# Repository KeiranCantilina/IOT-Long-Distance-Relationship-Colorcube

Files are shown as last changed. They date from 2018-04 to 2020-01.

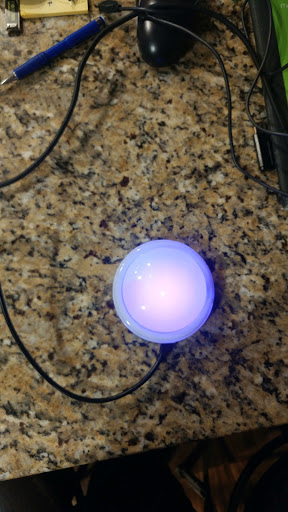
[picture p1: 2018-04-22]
prototype colorcube.jpg

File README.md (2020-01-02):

# IOT Long Distance Relationship Colorcube
Design for a pair of networked RGB LED widgets that synchronously change color when one of them is squeezed.

I know there are similar things out there, but I'm intentionally forging forward without looking at other implementations in order to force myself to properly learn this stuff.

~~The current design uses a Wildfire v4 (an Arduino-flavor board made by WickedDevice). This device is not super well-suited to this project,
but it has an integrated ESP8266 wifi chip and a microSD thingy and also I have like 5 of them somehow, so that's what I'm using.~~

The newest version of the design uses an Adafruit Feather HUZZAH ESP8266 board. In contrast to the Wildfire, this board is very well suited to this project and costs less than $20. Instead of a generic RGB LED driven using PWM, the newest hardware revision now uses a "NeoPixel" WS2812 RGB LED breakout board. 

HARDWARE DESIGN (Prototype completed!)
---------------------
The devices each consist of a plastic 3D printed base (containing the microcontroller board) with an RGB led protruding from the base. The LED is covered by a silicon cube-shaped diffuser, which also contains a motion sensor to detect squeezing. Power is provided by 5V USB. A small Li-ion battery might be included.

SOFTWARE DESIGN (Done! See Prototype_ESP8266_V2.ino)
---------------------
The software side of things should be pretty simple. The Wildfire collects sensor data and randomly generates 3 values (for RGB) when a squeeze is detected. These values are published via MQTT to a feed on io.adafruit.com. The device is also subscribed to the same feed, and will collect both values it publishes and values from other cubes. When data is recieved through the subscription, the device parses the data and uses the RGB values to change its own color.

ENCLOSURE DESIGN (Prototype completed! See 3mf files)
---------------------
The enclosure consists of a two-part 3D printed shell with holes for wires (and to provide access to the USB port) and standoffs for boards. There is a sort of brim thingy to hold the silicone cube using a friction fit. This design will probably go through several refinement stages. Holes in the standoffs (for screws) will be drilled by hand because the 3D printer is bad at holes.

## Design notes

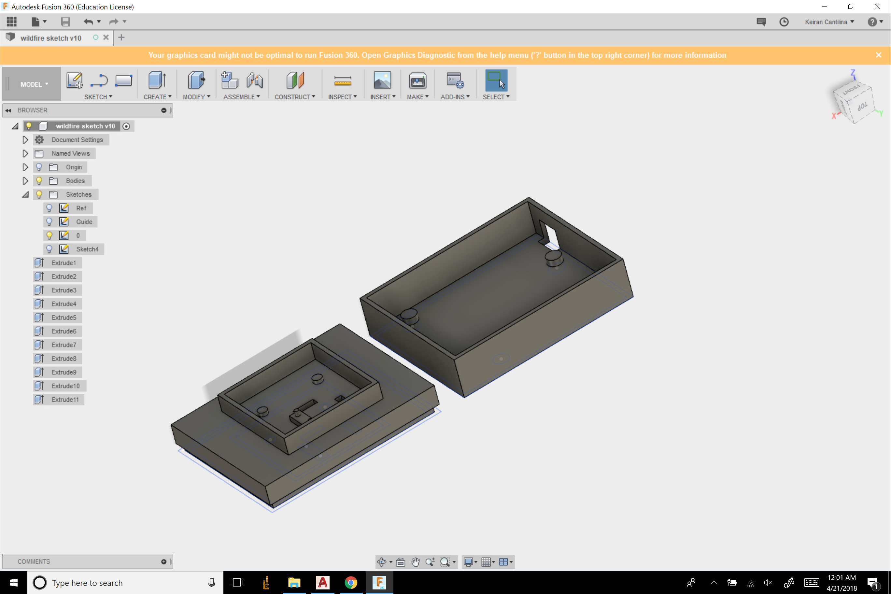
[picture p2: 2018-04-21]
enclosure design in progress.png

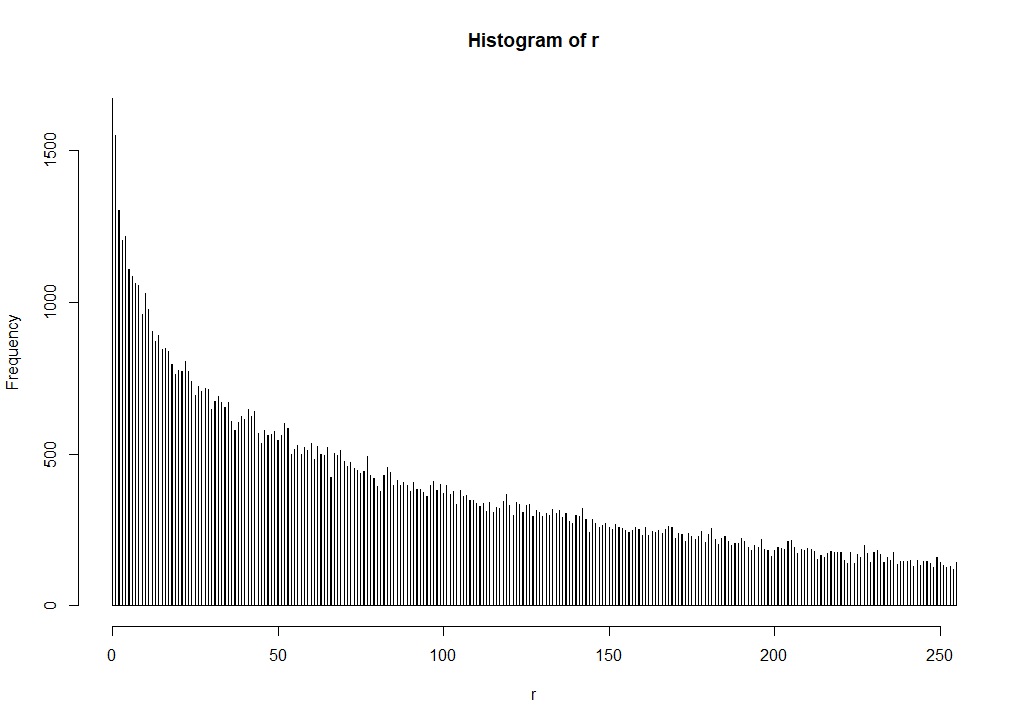
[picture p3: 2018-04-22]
Histogram of red.png

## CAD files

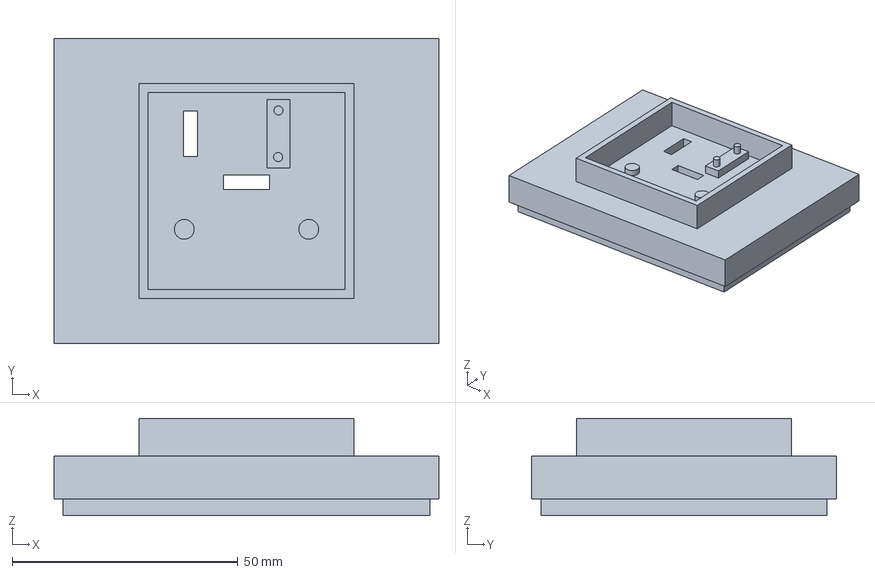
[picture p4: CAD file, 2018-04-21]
UM2E_colorcube_top_V1.3mf
85.3 x 67.6 x 21.6 mm

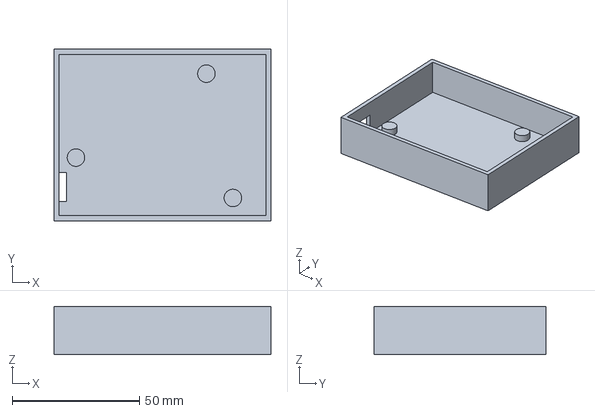
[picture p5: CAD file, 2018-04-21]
UM2E_colorcube_bottom_V1.3mf
85.3 x 67.6 x 19.0 mm

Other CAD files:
wildfire sketch.dwg

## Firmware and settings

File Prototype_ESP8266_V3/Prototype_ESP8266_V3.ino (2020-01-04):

/*This is the third generation codebase for the LED Relationship Light Project.
  This codebase is compatible with the Adafruit Feather HUZZAH (and theoretically with other ESP8266-based boards) and NeoPixel RGB-LEDs.
  Adafruit.io is used as the MQTT server, and the WifiManager library is used to handle user-side Wifi config via a captive portal that pops up
  if connection fails.

  This third generation code differs from the second generation in that it includes some fun extras, like crossfading transitions.
    
  The most recent hardware uses these WS2812 Neopixels: https://www.adafruit.com/product/1612

  Pins used:
  IDE pin 14 (marked on board as 14)(Physical Pin 5): WS2812 DataIn
  VBUS (marked on board as USB)OR 3V3(if 5V fails)  : WS2812 Power In
  GND                                               : WS2812 GND
  IDE pin 4 (marked on board as 4)(Physical pin D13): Button GND
  IDE pin 5 (marked on board as 5)(Physical pin D14): Button Detect (Interrupt attached and using internal pullup)
  IDE pin 0 (marked on board as 0)(Physical pin D3) : Status LED (built-in power LED, write HIGH to turn off ONLY AFTER BOOT)
  
*/


/********************* Libraries ****************************/
#include <ESP8266WiFi.h>          //ESP8266 Core WiFi Library (you most likely already have this in your sketch)

#include <DNSServer.h>            //Local DNS Server used for redirecting all requests to the configuration portal
#include <ESP8266WebServer.h>     //Local WebServer used to serve the configuration portal
#include <WiFiManager.h>          //https://github.com/tzapu/WiFiManager WiFi Configuration Magic

#include <Adafruit_MQTT.h>
#include <Adafruit_MQTT_Client.h> // Found at https://github.com/adafruit/Adafruit_MQTT_Library

#include <Adafruit_NeoPixel.h>

/********************* LED Setup ****************************/
#define NEOPIXEL_PIN 14 // NeoPixels are connected to this pin
#define LED_COUNT 1
#define BUTTON_PIN 5
#define BUTTON_GND 4
#define DEBOUNCE_DELAY 100 // in ms
#define STATUS_LED 0

Adafruit_NeoPixel RGBlight(LED_COUNT, NEOPIXEL_PIN, NEO_GRB + NEO_KHZ800); // Declare Neopixel object

uint32_t last_interrupt_time = 0;
uint8_t led_status = 0; //  Debugging LED flag
volatile int flag = 0;
volatile long times_run = 0;

int current_color[3] = {0,0,0};
int blue_array[3] = {0,0,255};
int red_array[3] = {255,0,0};

/************************* Adafruit.io Setup *********************************/
#define AIO_SERVER      "io.adafruit.com"
#define AIO_SERVERPORT  1883                   // use 8883 for SSL
#define AIO_USERNAME    "Keirancantilina"
#define AIO_KEY         "5526f708aeb648ea907a38d95af2b5a2"

/************ Global State (you don't need to change this!) ******************/
// Create an ESP8266 WiFiClient class to connect to the MQTT server.
WiFiClient client;
// or... use WiFiFlientSecure for SSL
//WiFiClientSecure client;

// Setup the MQTT client class by passing in the WiFi client and MQTT server and login details.
Adafruit_MQTT_Client mqtt(&client, AIO_SERVER, AIO_SERVERPORT, AIO_USERNAME, AIO_KEY);

/****************************** Feeds ***************************************/

// Setup a feed called 'publish_feed' for publishing.
// Notice MQTT paths for AIO follow the form: <username>/feeds/<feedname>
Adafruit_MQTT_Publish publish_feed = Adafruit_MQTT_Publish(&mqtt, AIO_USERNAME "/feeds/keiran-block");

// Setup a feed called 'subscribe_feed' for subscribing to changes.
Adafruit_MQTT_Subscribe subscribe_feed = Adafruit_MQTT_Subscribe(&mqtt, AIO_USERNAME "/feeds/keiran-block");


// Bug workaround for Arduino 1.6.6, it seems to need a function declaration
// for some reason (only affects ESP8266, likely an arduino-builder bug).
void MQTT_connect();


void setup() {

/********************* RGB and Button Init ****************************/
  // Initialize Neopixel
  RGBlight.begin();
  RGBlight.clear();
  RGBlight.show();
  
  // Setup the button with an internal pull-up :
  pinMode(BUTTON_PIN,INPUT_PULLUP);

  // Setup interrupt handling and LED for debug purposes
  //pinMode(LED_BUILTIN, OUTPUT);
  attachInterrupt(digitalPinToInterrupt(BUTTON_PIN), isr_handler, CHANGE); // CHANGE for dome lights, RISING for little button switches
  pinMode(STATUS_LED, OUTPUT);

  // This is our fake ground connection for the switch
  pinMode(BUTTON_GND, OUTPUT);
  digitalWrite(BUTTON_GND, LOW);

  // Start with LED red to show setup
  RGBlight.setPixelColor(0,RGBlight.gamma32(RGBlight.Color(red_array[0],red_array[1],red_array[2])));
  RGBlight.show();
  memcpy(current_color,red_array,sizeof(current_color));

/********************* Serial Setup ****************************/  
  //Initialize Serial comms
  Serial.begin(115200);

  //Give things time to warm up (this is purely magical thinking, I know)
  delay(10);
  Serial.println(F("Keiran's Long-Distance Friendship Cube"));
  
/********************* Wifi Setup ****************************/
  //Initialize WifiManager captive portal
  WiFiManager wifiManager;

  //Callback to function that executes right before config mode
  wifiManager.setAPCallback(configModeCallback);

  //first parameter is name of access point, second is the password
  wifiManager.autoConnect("ESP8266_KKC", "password");

  Serial.println("WiFi connected! Yay");
/********************* END Wifi Setup ****************************/

  // Setup MQTT subscription for subscribe_feed.
  mqtt.subscribe(&subscribe_feed);
}



//Initialize variable used for payload value (RGB color)
volatile long x=0;


// Main program loop
void loop() {
  
  //THis used to be a function but for whatever reason it broke mqtt connection even before it was ever called...somehow it works just pasted in...
  // x = rand_color();

  //Randomly generate RGB values for output as the payload. Values are 0-255 with 111 added to eliminate problems with 0 padding.
  long red_int = random(111,366);
  long green_int = random(111,366);
  long blue_int = random(111,366);

  long million = 1000000;
  long thousand = 1000;
  
  // Ints get concatenated together into the payload "string". For whatever reason strings and chars are no good so this whole thing is a giant long. WHYYYY
  x = (red_int*million)+(green_int*thousand)+(blue_int);
  
  mqtt.subscribe(&subscribe_feed);
  // this is our 'wait for incoming subscription packets' busy subloop
  // try to spend your time here
  
  // Ensure the connection to the MQTT server is alive (this will make the first
  // connection and automatically reconnect when disconnected).  See the MQTT_connect
  // function definition further below.
  MQTT_connect();
  

  Adafruit_MQTT_Subscribe *subscription;

  
  
  while (flag == 0 && (subscription = mqtt.readSubscription(1000))) {
    if (subscription == &subscribe_feed) {
      Serial.println();
      Serial.print(F("Message recieved: "));
      Serial.println((char *)subscribe_feed.lastread);
      Serial.println();

      // Write received color to LED
      int new_color[3];
      new_color[0] = string_to_red((char *)subscribe_feed.lastread)-111;
      new_color[1] = string_to_green((char *)subscribe_feed.lastread)-111;
      new_color[2] = string_to_blue((char *)subscribe_feed.lastread)-111;


      // LED crossfade (is inline because it was too slow as a function, for some reason)
      int greatest;
      int color_difference[3] = {new_color[0]-current_color[0],new_color[1]-current_color[1],new_color[2]-current_color[2]};
  
      if(abs(color_difference[0])>= abs(color_difference[1])){
        if(abs(color_difference[0])>= abs(color_difference[2])){
          greatest = color_difference[0];
        }
        else{
          greatest = color_difference[2];
         }
      }
      else{
        if(abs(color_difference[1])>= abs(color_difference[2])){
          greatest = color_difference[1];
        }
        else{
          greatest = color_difference[2];
        }
      }
  
      for (int i=0; i< abs(greatest); i++){
        for (int j=0; j<3;j++){
          if (current_color[j] != new_color[j]){
            current_color[j] = current_color[j] + sgn(color_difference[j]);
          }
        }

        RGBlight.setPixelColor(0,RGBlight.gamma32(RGBlight.Color(current_color[0],current_color[1],current_color[2])));
        RGBlight.show();
        delay(10);
      }
      // ---------------------------------------------------------------------------------------
    }  
  }

  //If first time running, turn LED blue to indicate ready status and turn off status red LED
  if (times_run == 0){
    RGBlight.setPixelColor(0,RGBlight.gamma32(RGBlight.Color(blue_array[0],blue_array[1],blue_array[2])));
    RGBlight.show();
    memcpy(current_color, blue_array, sizeof(current_color));
    
    digitalWrite(STATUS_LED, HIGH);
  }
  
  if (flag == 1){
    //x = rand_color();
    Serial.print(F("\nSending color value: "));
    Serial.print(x);
    Serial.print("...");
    //if (! publish_feed.publish((char *)x)) {
    char buffer [10];
    int ret = snprintf(buffer, sizeof(buffer), "%ld", x);
    char * const p = buffer;
    if (! publish_feed.publish(p)) {
      Serial.println(F("Failed"));
      Serial.println();
    } else {
      Serial.println(F("OK!"));
      Serial.println();
    }
    flag = 0;
  }
    

  Serial.println("No message so far! Will look again...");

  // Increment times run counter
  if(times_run == 0){
    times_run++;
  }
  
  
  // ping the server to keep the mqtt connection alive
  // NOT required if you are publishing once every KEEPALIVE seconds
  
//  if(! mqtt.ping()) {
//    mqtt.disconnect();
//  }
  
}




// Function to connect and reconnect as necessary to the MQTT server.
// Should be called in the loop function and it will take care if connecting.
void MQTT_connect() {
  int8_t ret;

  // Stop if already connected.
  if (mqtt.connected()) {
    return;
  }

  Serial.print("Connecting to MQTT...");

  uint8_t retries = 3;
  
  while ((ret = mqtt.connect()) != 0) { // connect will return 0 for connected
       Serial.println(mqtt.connectErrorString(ret));
       Serial.println("Retrying MQTT connection in 5 seconds...");
       mqtt.disconnect();
       delay(5000);  // wait 5 seconds
       retries--;
       if (retries == 0) {
         RGBlight.setPixelColor(0,RGBlight.gamma32(RGBlight.Color(red_array[0],red_array[1],red_array[2]))); // Red light for error
         RGBlight.show();
         memcpy(current_color,red_array,sizeof(current_color));
         while (1);
       }
  }
  Serial.println("MQTT Connected!");
  Serial.println();
}



// Functions to take string with color data and turn it into rgb values
int string_to_red(char color_string[]){
  char r[]={0,0,0};
  for (byte q = 0; q < 3; q = q + 1) {
    r[q] = color_string[q];
  }
  return atol(r);
}
int string_to_green(char color_string[]){
  char g[]={0,0,0};
  for (byte q = 0; q < 3; q = q + 1) {
    g[q] = color_string[q+3];
  }
  return atol(g);
}
int string_to_blue(char color_string[]){
  char b[]={0,0,0};
  for (byte q = 0; q < 3; q = q + 1) {
    b[q] = color_string[q+6];
  }
  return atol(b);
}



// Interrupt handling
ICACHE_RAM_ATTR void isr_handler() {
  uint32_t interrupt_time = millis();
  // Debounce
  if (interrupt_time - last_interrupt_time > DEBOUNCE_DELAY) {
    led_status = !led_status;
    //digitalWrite(LED_BUILTIN, led_status);  // Enable this for visual debugging switch/interrupt stuff
    flag = 1;
  }
  last_interrupt_time = interrupt_time;
}



// Function for handling failed wifi connections
void configModeCallback (WiFiManager *myWiFiManager) {
  Serial.println("Entered config mode");
  Serial.println(WiFi.softAPIP());
  // Placeholder for future callback code here (debug, maybe)
  Serial.println(myWiFiManager->getConfigPortalSSID());
}



// Sign finding function
inline int sgn(int val) {
  if (val < 0) return -1;
  if (val==0) return 0;
  return 1;
}

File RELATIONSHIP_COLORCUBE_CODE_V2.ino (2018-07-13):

/***************************************************
 * Wicked Device Wildfire v4 MQTT-Adafruit.io Example
 * 
 * 
 * This is the Adafruit MQTT Library ESP8266 Example, 
 * modified to work on the Wildfire v4 boards made by WickedDevice
 * (http://shop.wickeddevice.com/) using the WickedDevice ESP8266 AT Client
 * library (found at https://github.com/WickedDevice/ESP8266_AT_Client).
 * 
 * This bit of code serves as an example of how to get the Wildfire v4 to 
 * work with io.adafruit.com using MQTT, since the code shipped with the 
 * boards (supporting the sparkfun.io Phant servers) is now obsolete.
 * 
 * Written/rehashed/butchered by Keiran Cantilina
 * Attribution-NonCommercial licesnse 3.0 United States (CC BY-NC 3.0 US)
 * 
 * Boilerplate from original Adafruit MQTT Library ESP8266 Example code
 * is included below. Please include both the above and below text in any
 * redistribution. 
 * 
 */


/***************************************************
  Adafruit MQTT Library ESP8266 Example

  Must use ESP8266 Arduino from:
    https://github.com/esp8266/Arduino

  Works great with Adafruit's Huzzah ESP board & Feather
  ----> https://www.adafruit.com/product/2471
  ----> https://www.adafruit.com/products/2821

  Adafruit invests time and resources providing this open source code,
  please support Adafruit and open-source hardware by purchasing
  products from Adafruit!

  Written by Tony DiCola for Adafruit Industries.
  MIT license, all text above must be included in any redistribution

 ****************************************************/
 
 
#include "Adafruit_MQTT.h"
#include "Adafruit_MQTT_Client.h" // Found at https://github.com/adafruit/Adafruit_MQTT_Library
#include <ESP8266_AT_Client.h> // Found at https://github.com/WickedDevice/ESP8266_AT_Client
#include <RGBLED.h> // Found at https://github.com/BretStateham/RGBLED
#include <EnableInterrupt.h>


// sketch must instantiate a buffer to hold incoming data
// 1500 bytes is way overkill for MQTT, but if you have it, may as well
// make space for a whole TCP packet
#define ESP8266_INPUT_BUFFER_SIZE (1500)
uint8_t input_buffer[ESP8266_INPUT_BUFFER_SIZE] = {0};     


/************************* Init LED & switch stuff****************************/

RGBLED rgbLed(9,10,8,COMMON_CATHODE); // 9,10,8 for smd led chip, 8,9,10 for through-hole
int LED_gnd = 11;

#define BUTTON_PIN 24
#define DEBOUNCE_DELAY 100 // in ms


uint32_t last_interrupt_time = 0;
uint8_t led_status = 0; //  Debugging LED flag
volatile int flag = 0;
volatile long times_run = 0;

/************************* WiFi Access Point *********************************/

#define NETWORK_SSID     "CasaDeColletta"
#define NETWORK_PASSWORD "secretpassword"

// Arduino digital the pin that is used to reset/enable the ESP8266 module
int esp8266_enable_pin = 23; 

// Serial1 is the 'stream' the AT command interface is on
Stream * at_command_interface = &Serial1;  


/************************* Adafruit.io Setup *********************************/

#define AIO_SERVER      "io.adafruit.com"
#define AIO_SERVERPORT  1883                   // use 8883 for SSL
#define AIO_USERNAME    "Keirancantilina"
#define AIO_KEY         "5526f708aeb648ea907a38d95af2b5a2"

/************ Global State (you don't need to change this!) ******************/

// Create an ESP8266 WiFiClient class to connect to the MQTT server.
//WiFiClient client;
// or... use WiFiFlientSecure for SSL
//WiFiClientSecure client;

// ORR...Wildfire client object
ESP8266_AT_Client esp(esp8266_enable_pin, at_command_interface); // instantiate the client object


// Setup the MQTT client class by passing in the WiFi client and MQTT server and login details.
Adafruit_MQTT_Client mqtt(&esp, AIO_SERVER, AIO_SERVERPORT, AIO_USERNAME, AIO_KEY);

/****************************** Feeds ***************************************/

// Setup a feed called 'photocell' for publishing.
// Notice MQTT paths for AIO follow the form: <username>/feeds/<feedname>
Adafruit_MQTT_Publish photocell = Adafruit_MQTT_Publish(&mqtt, AIO_USERNAME "/feeds/keiran-block");

// Setup a feed called 'onoff' for subscribing to changes.
Adafruit_MQTT_Subscribe onoffbutton = Adafruit_MQTT_Subscribe(&mqtt, AIO_USERNAME "/feeds/keiran-block");

/*************************** Sketch Code ************************************/

// Bug workaround for Arduino 1.6.6, it seems to need a function declaration
// for some reason (only affects ESP8266, likely an arduino-builder bug).
void MQTT_connect();

void setup() {

  // Save RGB instance data as string to variable (in case it needs to be output for debugging)
  String ledType = (rgbLed.commonType==0) ? "COMMON_CATHODE" : "COMMON_ANODE";
  
  // Setup the button with an internal pull-up :
  pinMode(BUTTON_PIN,INPUT_PULLUP);

  // Setup interrupt handling and LED for debug purposes
  pinMode(LED_BUILTIN, OUTPUT);
  enableInterrupt(BUTTON_PIN, isr_handler, CHANGE); // CHANGE for dome lights, RISING for little button switches

  // This is our fake ground connection for the rgb led
  pinMode(LED_gnd, OUTPUT);
  digitalWrite(LED_gnd, LOW);

  // Start with LED red to show setup
  rgbLed.writeRGB(255,0,0);
  
  Serial.begin(115200);
  delay(10);
  Serial1.begin(115200);              // AT command interface

  // For just in case of network debugging needs
  char ip_str[16] = {0};
  char mac_str[18] = {0};
  uint8_t mac_addr[6] = {0};
  uint32_t ip_addr = 0;
  
  esp.setInputBuffer(input_buffer, ESP8266_INPUT_BUFFER_SIZE); // connect the input buffer up
  esp.reset();                                                 // reset the module
  
  
  Serial.println(F("Keiran's Long-Distance Friendship Cube"));

  // Connect to WiFi access point.
  Serial.print("Set Mode to Station...");
  esp.setNetworkMode(1);
  Serial.println("OK");
  Serial.print("Connecting to ");
  Serial.print(NETWORK_SSID);
  Serial.print("...");
  esp.connectToNetwork(NETWORK_SSID, NETWORK_PASSWORD, 60000, NULL); 
  Serial.println("OK");  
  Serial.println("WiFi connected! Yay");
  
  // Setup MQTT subscription for onoff feed.
  //mqtt.subscribe(&onoffbutton);
}

//Initialize variable used for payload value (RGB color)
volatile long x=0;
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

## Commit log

2018-04-18 Prototype MQTT code for WildfireV4 and adafruit.io
    * This is the Adafruit MQTT Library ESP8266 Example,
    * modified to work on the Wildfire v4 boards made by WickedDevice
    * (http://shop.wickeddevice.com/) using the WickedDevice ESP8266 AT Client
    * library (found at https://github.com/WickedDevice/ESP8266_AT_Client).
    *
    * This bit of code serves as an example of how to get the Wildfire v4 to
    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
2018-04-19 Update Receive_color_mqtt
    Added successful interrupt driven button routine to send arbitrary data
2018-04-20 Update RX-TX-color-mqtt.ino
    moved ready status blue light to after first subscription check
    reduced subscription check interval from 2000 to 1000 (might be more unstable...)
    [RX-TX-color-mqtt.ino]
2018-04-21 Prototype 3D printed enclosure design
    [UM2E_colorcube_bottom_V1.3mf, UM2E_colorcube_top_V1.3mf, wildfire sketch.dwg]
2018-04-21 Update README.md
    Added enclosure description
2018-04-22 Added option for maintained switches and SMD LEDs
2019-09-26 First version of prototype code that doesn't crash the chip. Yay!
    [Debugging_sketch.ino, Library_test.ino, MQTT_Cred_input_test.ino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]
2020-01-02 Updated code to final version using Neopixel
    Tested to work correctly!
    [Prototype_ESP8266_V2.ino]
